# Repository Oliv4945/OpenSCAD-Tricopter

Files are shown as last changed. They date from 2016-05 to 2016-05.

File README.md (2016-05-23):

# OpenSCAD-Tricopter    -    La FraiseVolante
A fully customizable 3D printed tricopter designed thanks to [OpenSCAD](http://www.openscad.org).  
The code is not cristal clear as it was my first "big" project in order to try OpenSCAD for such things, but all parameters can be changed in the file `Variables.scad`, I tried to add warnings in the log for illogical values but always check after modifications. Also, the rod length will be displayed in the log too.

The tricopter works well but the documentation is a work in progress. If needed ask me ;-)

# Files
There is 4 categories
 * Helpers
  * Elements.scad => Contains all elements usefull for design (batteries, ESC, receiver, etc)
  * CCC3DBox.scad => A CC3D case I grabbed [here](http://www.thingiverse.com/thing:95644). Not tested, I only used it for design
 * Assembly.scad => Assembly file, calculates required carbon rod length
 * Variables.scad => All parameters should be tunned here
 * And files with pieces to print
  * ArmHolders.scad
  * BasePlates.scad
  * MotorSupport.scad

# Parts to print
 * armBearingsSeparator_1.stl => 1
 * armBearingsSeparator_2.stl => 1
 * armHolderFront.stl => 2
 * armHolderRearFront.stl => 1
 * armHolderRearRear.stl => 1
 * basePlateLow.stl => 1
 * basePlateMiddle.stl => 1
 * basePlateServo.stl => 1
 * batteryHolder.stl => 1
 * ESCHolder.stl => 2
 * feetPropSaver.stl => Optionnal
 * motorSupport.stl => 3
 * motorSupportFeet.stl => Optionnal

# Parts to buy
 * 3 Motors - 1806 about 2300 kv. I used DYS BE1806-2300kv
 * 3 ESC -  12A. I used [12A Afro ESC](https://www.hobbyking.com/hobbyking/store/%5F%5F62955%5F%5FAfro%5FESC%5F12Amp%5FBEC%5FUltraLite%5FMultirotor%5FESC%5FV3%5FSimonK%5FFirmware%5FUK%5FWarehouse%5F.html)
 * 5030 propellers. Whatever you find, clockwise and anti-clockwise
 * 1 servo motor, the [TGY-9025](https://www.hobbyking.com/hobbyking/store/%5F%5F31879%5F%5FTurnigy%5F8482%5FTGY%5F9025MG%5FMG%5FServo%5F1%5F8kg%5F0%5F09sec%5F11g%5FUK%5FWarehouse%5F.html) works fine and I design the support for it.
 * 10mm OD holow carbon fiber tube - about 35 cm. I used [this one](https://www.hobbyking.com/hobbyking/store/%5F%5F26195%5F%5FCarbon%5FFiber%5FTube%5Fhollow%5F10x750mm%5FUK%5FWarehouse%5F.html)
 * Batteries - 3S from 1.3Ah to 2.2Ah. [This battery](https://www.hobbyking.com/hobbyking/store/%5F%5F32111%5F%5FZIPPY%5FCompact%5F1300mAh%5F3S%5F25C%5FLipo%5FPack%5FUK%5FWarehouse%5F.html) is great, 2.2A works too but it is a bit heavy
 * 1 micro receiver. I use FrSky D4R-II 2.4G 4CH ACCST Telemetry flashed in 8 channels CPPM.
 * 1 flight controller. I used a cheap [CC3D](http://www.openpilot.org/products/openpilot-coptercontrol-platform)
 * 2 bearings - size 10x15x4 mm. Mine are 9.8 inner mm instead of 10, that is why I do not put carbon rod inside but designed a part.
 * Optionnal
  * Video for FPV
   * Holder for a [Sony 600 TVL](http://www.surveilzone.com/fpv/fpv-camera/sony-super-had-ccd-600tvl-fpv-ir-block-camera-2.8mm-lens)
   * Video transmitter
  * Bluetooth to ease configuration, especially if you but the USB port behind the servo like me (Not recommended :p)

Screws are all 3 mm, mainly 6 an 8 mm long (TBC). You can use metal screws but nylon will save weight, and especially act as fuses. It works well !

# Others
There are comments in code to help to understand, but from time to time some names are not explicits. If you change them PR are welcome !  
Thank to the [Brocopter](http://www.thingiverse.com/thing:413639) for some inspiration, especially to add some tape on the rods in order to adjust the motor support.

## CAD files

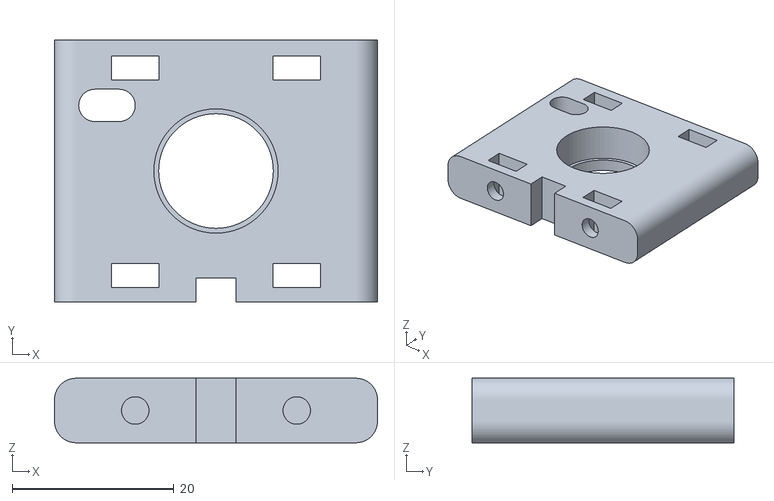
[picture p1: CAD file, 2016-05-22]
TriCopter/armHolderRearFront.stl
40.0 x 32.5 x 8.00

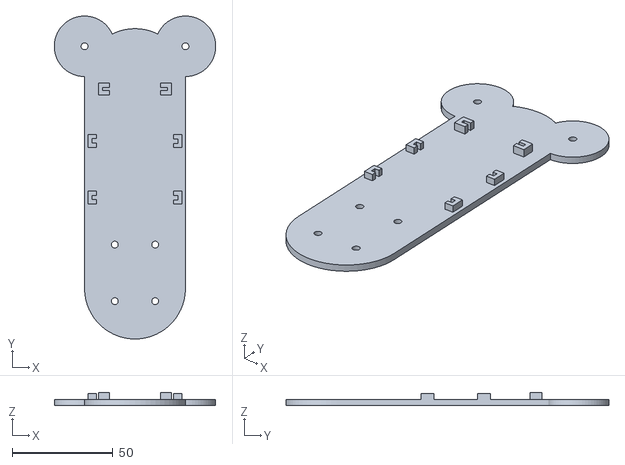
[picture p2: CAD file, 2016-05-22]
TriCopter/basePlateLow.stl
80.0 x 160.0 x 6.50

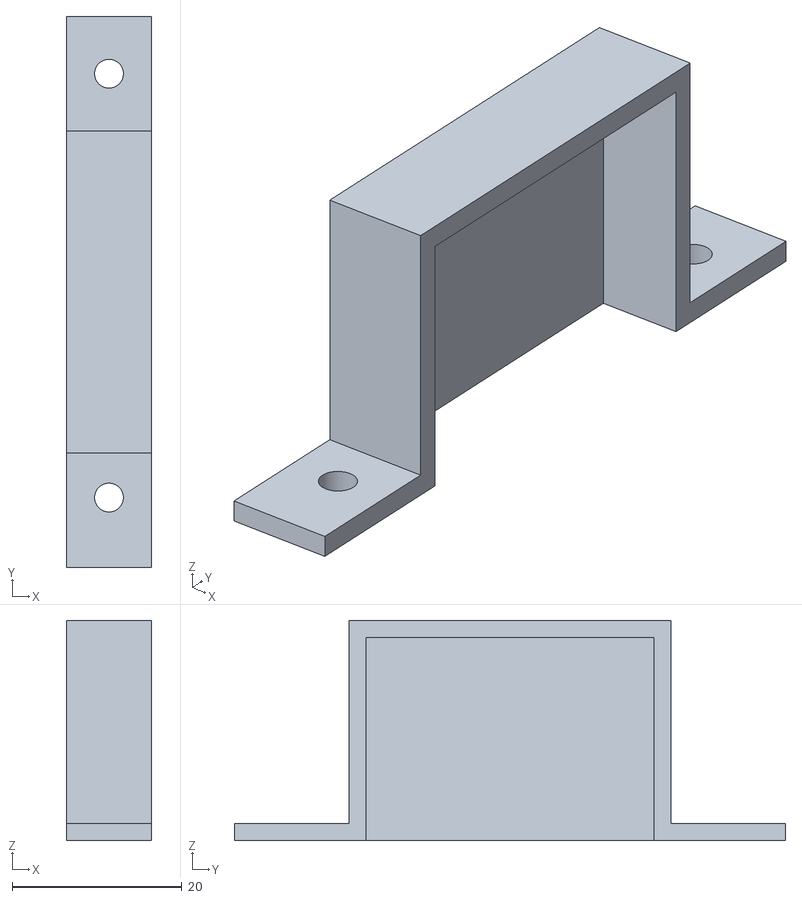
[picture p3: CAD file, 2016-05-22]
TriCopter/batteryHolder.stl
10.0 x 65.0 x 26.0

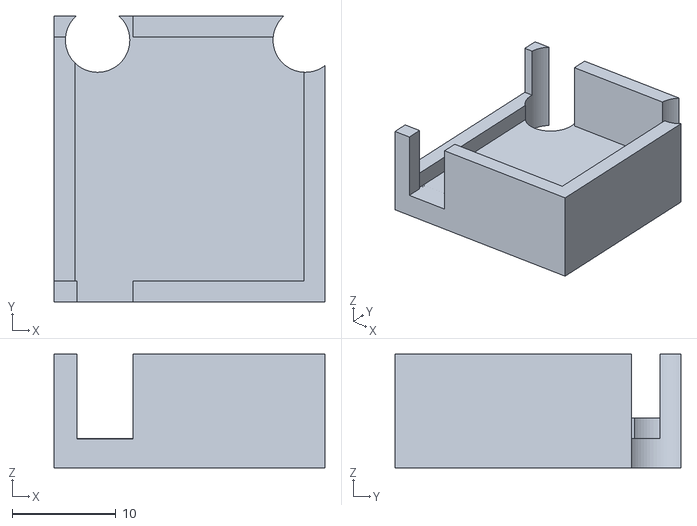
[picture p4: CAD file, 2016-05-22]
TriCopter/basePlateServo.stl
26.1 x 27.5 x 10.9

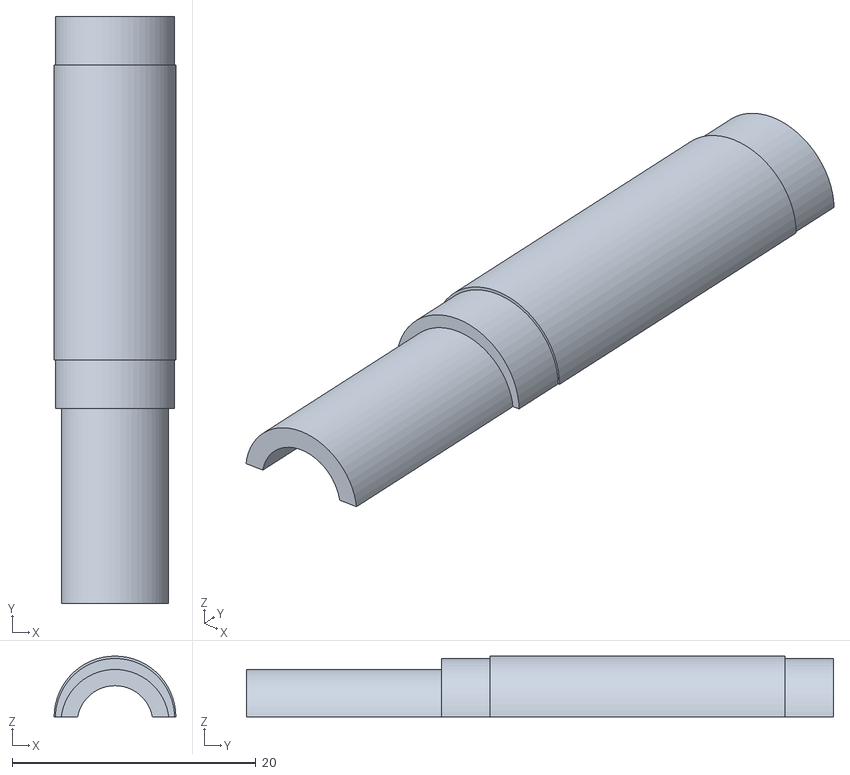
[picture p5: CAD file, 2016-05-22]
TriCopter/armBearingsSeparator_1.stl
10.0 x 48.2 x 5.00

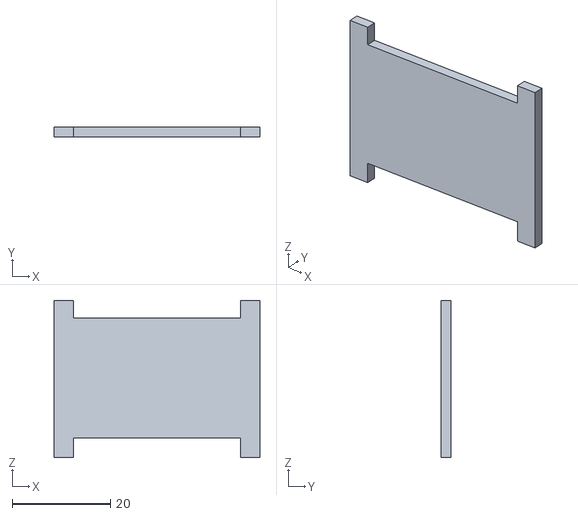
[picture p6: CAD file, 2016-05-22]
TriCopter/ESCHolder.stl
42.0 x 2.00 x 32.1

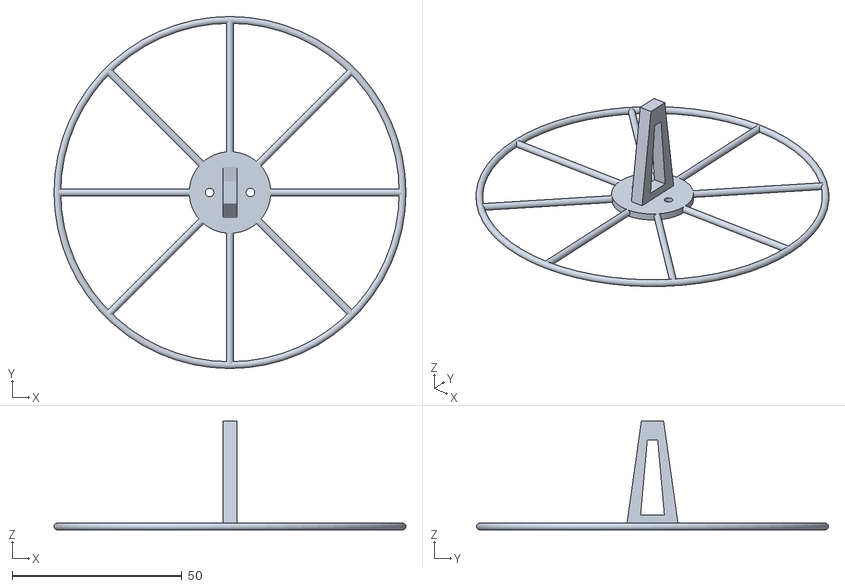
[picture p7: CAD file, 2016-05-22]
TriCopter/feetPropSaver.stl
103.6 x 103.6 x 32.0

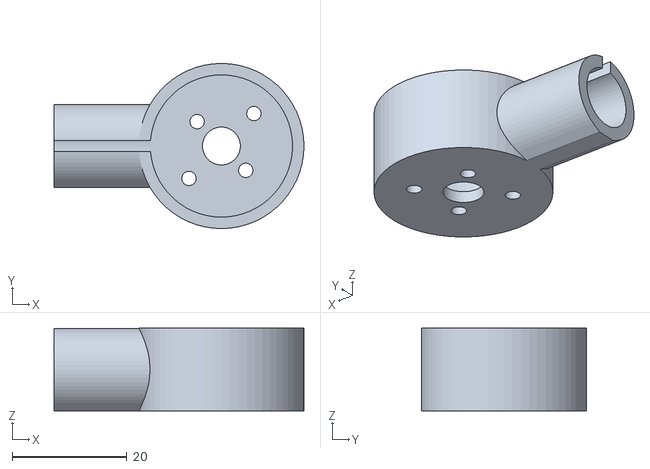
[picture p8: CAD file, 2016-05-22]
TriCopter/motorSupport.stl
43.6 x 28.8 x 14.4

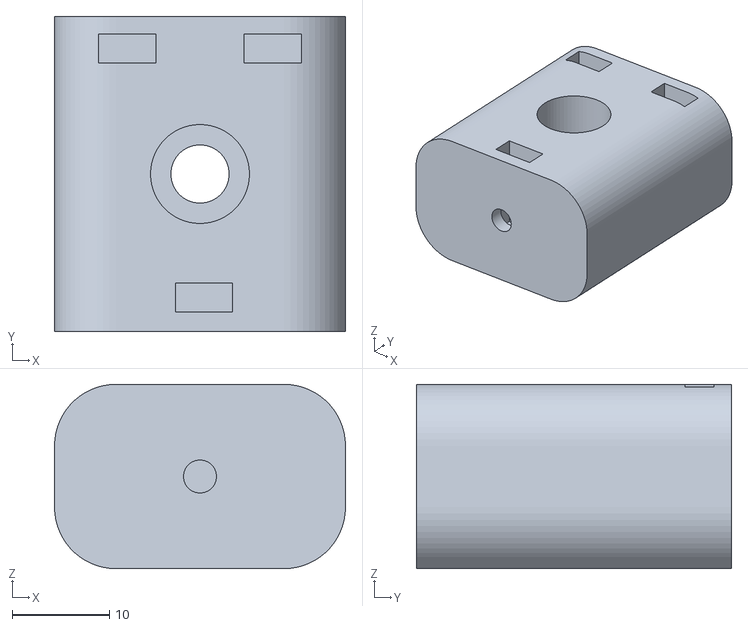
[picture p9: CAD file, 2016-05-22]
TriCopter/armHolderFront.stl
30.0 x 32.5 x 19.0

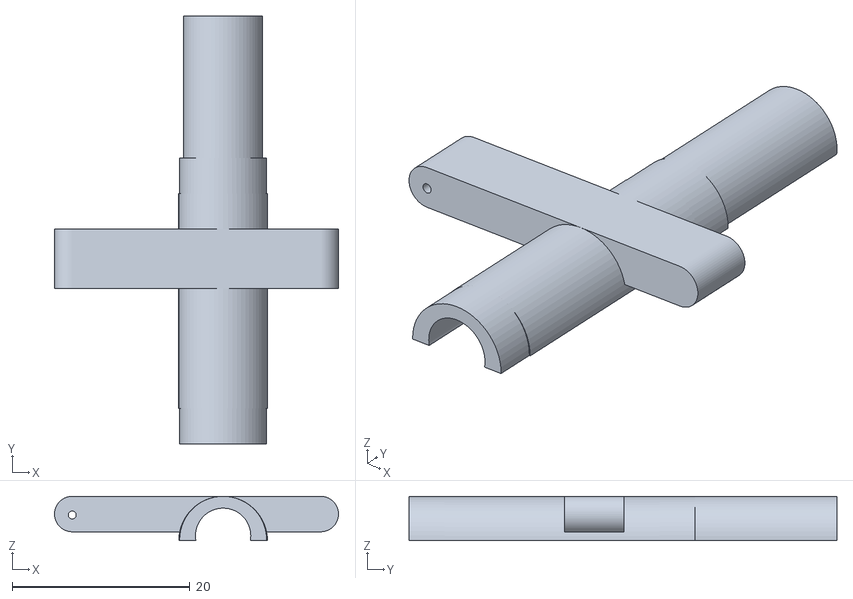
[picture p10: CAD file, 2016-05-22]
TriCopter/armBearingsSeparator_2.stl
32.0 x 48.2 x 5.00

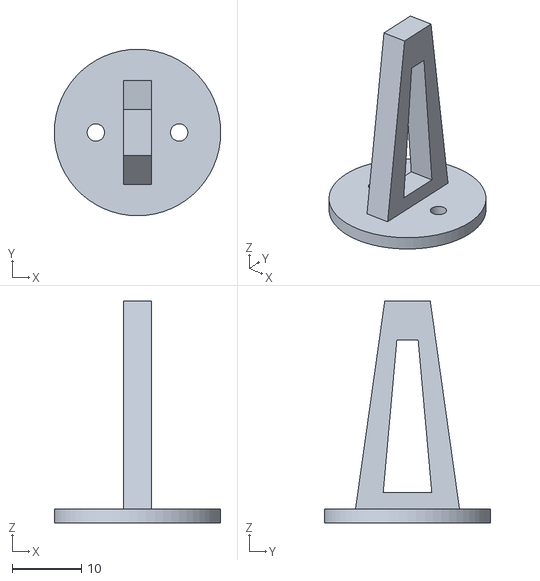
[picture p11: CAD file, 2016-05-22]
TriCopter/motorSupportFeet.stl
24.0 x 24.0 x 32.0

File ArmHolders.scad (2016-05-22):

// Include needed libraries
include <Variables.scad>;
use <Elements.scad>;

// Defines if we want a 'printable file' or a view with elements (motors...)
RENDER = 0;
PRINT = 1;
ASSEMBLY = 2;
view = ASSEMBLY;




module armHolderFront() {
  // Generates warning if needed
  if ( (armScrewLength-basePlateT+wallT+armOD/2)>armHolderH/2 ) {
    echo( "WARNING - Screw to long/arm radius to big, or arm holder not height enough" );
  }
  if ( (basePlateT==(wallT+clearance)) ) {
    echo( "WARNING - Front arm stops have same thickness than baase plate, be carrefull with difference function" );
  }
  
  difference() {
    union () {
      // Add - Main body
      roundedBox( [armHolderFrontW, armHolderFrontD, armHolderH], armHolderFrontD/3);
    }
    // Remove - Arm
    translate( [armHolderFrontW/2, -1, armHolderH/2] )
      rotate( [0, 90, 90] ) cylinder( r=armOD/2+clearance/2, h=armInsideSupport+1 );
    // Remove - Hole for wires
    translate( [armHolderFrontW/2, -1, armHolderH/2] )
      rotate( [0, 90, 90] ) cylinder( r=armOD/2-wallT, h=armInsideSupport*2 );
    
    // Remove - Bottom screw
    translate( [armHolderFrontW/2, armHolderFrontD/2, -basePlateT+1] )
      cylinder( r=armScrewOD/2+clearance, h=armScrewLength+1 );
    // Remove - Top screws
    translate( [armHolderFrontW/4, armHolderFrontD/2, armHolderH+basePlateT-armScrewLength-1] )
      cylinder( r=armScrewOD/2+clearance, h=armScrewLength+1 );
    translate( [armHolderFrontW*3/4, armHolderFrontD/2, armHolderH+basePlateT-armScrewLength-1] )
      cylinder( r=armScrewOD/2+clearance, h=armScrewLength+1 );
    // Remove - Bottom nut
    translate( [(armHolderFrontW-armScrewNutW+clearance*2)/2, -armHolderFrontD/2+armScrewNutW/(sqrt(3)/2)/2+clearance, (armScrewLength-basePlateT)-(armScrewNutH+clearance*2)] )
      cube( [armScrewNutW+clearance*2, armHolderFrontD, armScrewNutH+clearance*2] );
    // Remove - Top nuts
    translate( [(armHolderFrontW/4-armScrewNutW/2-clearance), -armHolderFrontD/2+armScrewNutW/(sqrt(3)/2)/2+clearance, armHolderH-(armScrewLength-basePlateT)+clearance] )
      cube( [armScrewNutW+clearance*2, armHolderFrontD, armScrewNutH+clearance*2] );
    translate( [(armHolderFrontW*3/4-armScrewNutW/2-clearance), -armHolderFrontD/2+armScrewNutW/(sqrt(3)/2)/2+clearance, armHolderH-(armScrewLength-basePlateT)+clearance] )
      cube( [armScrewNutW+clearance*2, armHolderFrontD, armScrewNutH+clearance*2] );
  }
}


module armHolderRear() {
  difference() {
    // Add - Main body
    roundedBox( [armHolderRearW, armHolderRearD, armHolderH], armHolderRearD/3);
    // Remove - Bearing holder
    translate( [armHolderRearW/2, -1, armHolderH/2] )
      rotate( [0, 90, 90] ) cylinder( r=armBearingOD/2-armBearingFlange, h=armHolderRearD+2 );
    translate( [armHolderRearW/2, armHolderRearD-armBearingBore-wallT, armHolderH/2] )
      rotate( [0, 90, 90] ) cylinder( r=armBearingOD/2+clearance, h=armHolderRearD+1 );
    // Remove - Screws
    translate( [armHolderRearW/4, armHolderRearD/2, -basePlateT+1] )
      cylinder( r=armScrewOD/2+clearance, h=armScrewLength+1 );
    translate( [armHolderRearW*3/4, armHolderRearD/2, -basePlateT+1] )
      cylinder( r=armScrewOD/2+clearance, h=armScrewLength+1 );
    translate( [armHolderRearW/4, armHolderRearD/2, armHolderH+basePlateT-armScrewLength-1] )
      cylinder( r=armScrewOD/2+clearance, h=armScrewLength+1 );
    translate( [armHolderRearW*3/4, armHolderRearD/2, armHolderH+basePlateT-armScrewLength-1] )
      cylinder( r=armScrewOD/2+clearance, h=armScrewLength+1 );
    // Remove - Nuts
    translate( [armHolderRearW/4-(armScrewNutW+clearance*2)/2, -1, (armScrewLength-basePlateT)-(armScrewNutH+clearance*2)] )
      cube( [armScrewNutW+clearance*2, armHolderRearD+2, armScrewNutH+clearance*2] );
    translate( [armHolderRearW*3/4-(armScrewNutW+clearance*2)/2, -1, (armScrewLength-basePlateT)-(armScrewNutH+clearance*2)] )
      cube( [armScrewNutW+clearance*2, armHolderRearD+2, armScrewNutH+clearance*2] );
    translate( [armHolderRearW/4-(armScrewNutW+clearance*2)/2, -1, armHolderH-(armScrewLength-basePlateT)+clearance] )
      cube( [armScrewNutW+clearance*2, armHolderRearD+2, armScrewNutH+clearance*2] );
    translate( [armHolderRearW*3/4-(armScrewNutW+clearance*2)/2, -1, armHolderH-(armScrewLength-basePlateT)+clearance] )
      cube( [armScrewNutW+clearance*2, armHolderRearD+2, armScrewNutH+clearance*2] );
    // Remove - Arm servo's zip tie
    translate( [armHolderRearW/2-zipTieW/2, -1, armHolderH-zipTieD] )
      cube( [zipTieW, armHolderRearD+2, zipTieD+1] );
  }
}


module armHolderRearFront() {
  difference() {
    armHolderRear();
    // Remove - Battery wires
    translate( [armHolderRearW/5-wallT*1.5, armHolderRearD+1, armHolderH/4] ) rotate( [90, 0, 0] )
    hull() {
      cylinder( r=wallT, h=armHolderRearD+2);
      translate( [wallT*1.5, 0, 0] )
        cylinder( r=wallT, h=armHolderRearD+2);
    }
  }
}

module armHolderRearRear() {
  difference() {
    armHolderRear();
    // Remove - Battery wires
    translate( [armHolderRearW*4/5, armHolderRearD+1, armHolderH/4] ) rotate( [90, 0, 0] )
    hull() {
      cylinder( r=wallT, h=armHolderRearD+2);
      translate( [wallT*1.5, 0, 0] )
        cylinder( r=wallT, h=armHolderRearD+2);
    }
  }
}

module armBearingsSeparator() {
  difference() {
    union() {
      // Add - main body
      translate( [0, (armOD-armBearingID)/2, 0] ) 
        cylinder( r=armBearingID/2, h=armBearingBore );
      translate( [0, 0, armBearingBore] ) 
        cylinder( r=armOD/2, h=armBearingsSeparatorLength+clearance+wallT*2 );
      translate( [0, (armOD-armBearingID)/2, armBearingBore+armBearingsSeparatorLength+clearance+wallT*2] ) 
        cylinder( r=armBearingID/2, h=armBearingBore );
      // Add - Improve printability & piano wire body
      hull() {
        translate( [armOD/2+wallT*3, armOD/2-wallT, wallT*2+armBearingBore] )
          cylinder( r=wallT, h=armBearingsSeparatorLength/3 );
        translate( [-armOD/2-wallT*6, armOD/2-wallT, wallT*2+armBearingBore] )
          cylinder( r=wallT, h=armBearingsSeparatorLength/3 );
      }
      // Add - Inner of carbon tube
      translate( [0, (armOD-armID)/2, -armBearingBore*4] ) 
        cylinder( r=armID/2, h=armBearingBore*4 );
    }
    // 8.9
    /*
    // Remove - Arm
    translate( [0, 0, -1] )
      cylinder( r=armOD/2+clearance/2, h=armBearingsSeparatorLength+wallT*2+2 );
    // Remove - Screws
    translate( [armOD/2+wallT*2, -wallT*2-1, armBearingsSeparatorLength/3/2+wallT*2] )
      rotate( [270, 0, 0] ) cylinder( r=armScrewOD/2, h=wallT*4+2 );
    translate( [-(armOD/2+wallT*2), -wallT*2-1, armBearingsSeparatorLength/3/2+wallT*2] )
      rotate( [270, 0, 0] ) cylinder( r=armScrewOD/2, h=wallT*4+2 );
    // Remove - Nuts
    translate( [armOD/2+wallT*2, -wallT*2-1, armBearingsSeparatorLength/3/2+wallT*2] )
      rotate( [270, 0, 0] ) cylinder( r=(armScrewNutW*sqrt(3)/2+clearance)/2, h=wallT+1, $fn=6 );
    translate( [-(armOD/2+wallT*2), -wallT*2-1, armBearingsSeparatorLength/3/2+wallT*2] )
      rotate( [270, 0, 0] ) cylinder( r=(armScrewNutW*sqrt(3)/2+clearance)/2, h=wallT+1, $fn=6 );
    */
    // Remove - Steel wire
    translate( [-armOD/2-wallT*6, armBearingID/2-wallT, 0] )
      cylinder( r=armYawSteelWireOD/2, h=armBearingsSeparatorLength );
    // Remove - Inside to allow wires
    // Add - Inner of carbon tube
      translate( [0, (armOD-armID)/2, -armBearingBore*4-1] ) 
        cylinder( r=armID/2-wallT/1.5, h=armBearingsSeparatorLength*4 );
  }
}
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

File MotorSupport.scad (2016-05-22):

// Include needed libraries
include <Variables.scad>;
use <Elements.scad>;

// Set number of facets for arcs
$fn=60;


// Defines if we want a 'printable file' or a view with elements (motors...)
RENDER = 0;
PRINT = 1;
ASSEMBLY = 2;
view = PRINT;


// General design
wallT = 2;
clearance = 0.2;

// Arm
armOD = 10;

// MotorSupports
/*motorOD = 23;
motorScrewOD = 2.1;
motorScrewAlignementD1 = 12;
motorScrewAlignementD2 = 16;
motorAxleOD = 6.2;
armInsideSupport = 20;
feetW = 15;
feetH = 30;
feetT = wallT*2;*/


module motorSupport() {
  supportH = armOD+wallT*2+clearance*2;
  motorCenter = motorOD/2+wallT+clearance+armInsideSupport;
  
  difference() {
    union() {
      // Add - Arm extension
      hull() {
        cylinder( r=supportH/2, h=armInsideSupport+(motorOD+wallT)/2 );
        translate( [-supportH/2, -supportH/4/2, 0] )    // Flat surface to improve printing
          cube( [wallT, supportH/4, armInsideSupport+(motorOD+wallT)/2] );
      }
      // Add - Motor support
      translate( [-supportH/2, 0, motorCenter] )
        rotate( [0, 90, 0] ) cylinder( r=motorOD/2+clearance*2+wallT, h=supportH );
    }
    // Remove - arm - X=0.01 is to avoid removing on same planen
    translate( [0.01, 0, -1] ) cylinder( r=armOD/2+clearance/2, h = armInsideSupport+motorOD/2+1 );
    // Remove - Motor hole
    translate( [-supportH/2+wallT, 0, motorCenter] )
      rotate( [0, 90, 0] ) cylinder( r=motorOD/2+clearance*2, h=supportH );
    // Remove - Motor screws
    translate( [-supportH/2+1, 0, motorCenter] ) rotate( [45, 0, 0] ) rotate( [0, 90, 0] ) {
      for( i = [90, 270] ) {
        rotate( [0, 0, i] ) translate( [motorScrewAlignementD1/2, 0, 0] )
        cylinder( r=motorScrewOD/2+clearance, h=wallT+2, center=true );
      }
      for( i = [0, 180] ) {
        rotate( [0, 0, i] ) translate( [motorScrewAlignementD2/2, 0, 0] )
        cylinder( r=motorScrewOD/2+clearance, h=wallT+2, center=true );
      }
    }
    // Remove - Wire insertion
    translate( [-armOD/2, -wallT/2, -1] )
      cube( [armOD+wallT+2, wallT, armInsideSupport*2] );
    // Remove - Motor axle
    translate( [-supportH+1, 0, motorCenter] ) rotate( [0, 90, 0] )
      cylinder( r=motorAxleOD/2+clearance, h=supportH+2 );
  }
}

module feet() {
  angle = 8;
  holeOD = 3;

  difference() {
    cube( [feetW, feetT, feetH] );
    translate( [-feetW*2, -1, 0] ) rotate( [0, angle, 0] )
      cube( [feetW*2*cos(angle), feetT*2, feetH*2] );
    translate( [feetW, -1, 0] ) rotate( [0, -angle, 0] )
      cube( [feetW*2*cos(angle), feetT*2, feetH*2] );
  }
}


module motorScrews() {
  motorScrewAlignementD = motorScrewAlignementD1;
  union() {
    translate( [motorScrewAlignementD/2, 0, -1 ] )
      cylinder( r=motorScrewOD/2+clearance, h=wallT+2 );
    translate( [-motorScrewAlignementD/2, 0, -1 ] )
      cylinder( r=motorScrewOD/2+clearance, h=wallT+2 );
  }
}

module motorSupportFeet() {
  difference() {
    union() {
      // Add - Support plate
      cylinder( r=motorOD/2, h=wallT );
      translate( [feetT/2, -feetW/2, wallT] ) 
        rotate( [ 0, 0, 90] ) feet( wallT=wallT, feetT=feetT, feetH=feetH );
    }
    // Remove - Motor screws
    motorScrews();
    // Remove - Feet decoration
    resize( [feetT+2, feetW-feetT*2, feetH-feetT*2] )
      translate( [feetT/2, -feetW/2, wallT+feetT] ) rotate( [ 0, 0, 90] ) feet( feetT=feetT );
  }
}

module feetPropSaver() {
  difference() {
    union() {
      // Add - Motor feet
      motorSupportFeet();
      // Add - Structure
      for( i = [0 : 360/8 : 360] ) {
        translate( [0, 0, wallT/2] ) rotate( [90, 0, i] )
          cylinder( h=propOD/2.5, r=wallT/2 );
      // Add - Structure's circle
     translate( [0, 0, wallT/2] ) rotate_extrude( convexity = 10, $fn = 60 )
       translate([propOD/2.5, 0, 0])
         circle( r=wallT/2 );
      }
    }
    // Remove - motor screws
    motorScrews();
  }
}


if ( view == PRINT ) {
  translate( [0, 0, (armOD+wallT*2+clearance*2)/2] )
    rotate( [ 0, 270, 180] ) motorSupport();
  !translate( [-20, 0, 0] ) motorSupportFeet();
  translate( [0, propOD/1.5, 0] ) feetPropSaver();
} 
if ( ( view == RENDER) || ( view == ASSEMBLY) ) {
  translate( [0, 0, 0] ) rotate( [ 0, 270, 180] ) motorSupport();
  translate( [motorOD/2+wallT+armInsideSupport, 0, -(armOD+wallT*2+clearance*2)/2+wallT] )
    rotate( [ 0, 0, 90] ) motorDYS_BE1806();
  translate( [motorOD/2+wallT+armInsideSupport, 0, -(armOD+wallT*2+clearance*2)/2] )
    rotate( [ 180, 0, 90] ) motorSupportFeet();
}

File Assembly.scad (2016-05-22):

// Include needed libraries
include <Variables.scad>;
include <Elements.scad>;
include <MotorSupport.scad>;
include <ArmHolders.scad>;
include <BasePlates.scad>;

// Defines if we want a 'printable file' or a view with elements (motors...)
view = -1;
// Define if the front arms are folded
viewFoldedArms = FALSE;

 
module armFrontL( armLength = 100 ) {
	union() {
		translate( [armHolderFrontD, 0, 0] ) rotate( [0, 0, 90] ) armHolderFront();
  	translate( [armHolderFrontD-armInsideSupport, armHolderFrontW/2, armHolderH/2] ) rotate( [0, 90, 0] )
    	color( "DarkSlateGray") hollowCylinder( OD=armOD, ID=armID, length = armLength );
		translate( [armHolderFrontD-armInsideSupport+armLength-armInsideSupport, armHolderFrontW/2, armHolderH/2] )
    	rotate( [ 0, 270, 180] ) motorSupport( armInsideSupport=armInsideSupport );
  	
		translate( [armHolderFrontD-armInsideSupport+armLength+clearance+wallT+motorOD/2, armHolderFrontW/2, -7.5+wallT+armHolderH/2] )
    	rotate( [ 0, 0, 0] ) motorDYS_BE1806();
  	translate( [armHolderFrontD-armInsideSupport+armLength+clearance+wallT+motorOD/2, armHolderFrontW/2, -7.5+armHolderH/2] )
    	rotate( [ 180, 0, 90] ) motorSupportFeet();
  	
	}
}

module armFrontR( armLength = 100 ) {
	union() {
		translate( [armHolderFrontD, armHolderFrontW, 0] ) rotate( [0, 0, 90] ) mirror( [1, 0, 0] ) armHolderFront();
  	translate( [armHolderFrontD-armInsideSupport, armHolderFrontW/2, armHolderH/2] ) rotate( [0, 90, 0] )
    	color( "DarkSlateGray") hollowCylinder( OD=armOD, ID=armID, length = armLength );
		translate( [armHolderFrontD-armInsideSupport+armLength-armInsideSupport, armHolderFrontW/2, armHolderH/2] )
    	rotate( [ 0, 270, 180] ) motorSupport( armInsideSupport=armInsideSupport );
  	
		translate( [armHolderFrontD-armInsideSupport+armLength+clearance+wallT+motorOD/2, armHolderFrontW/2, -7.5+wallT+armHolderH/2] )
    	rotate( [ 0, 0, 0] ) motorDYS_BE1806();
  	translate( [armHolderFrontD-armInsideSupport+armLength+clearance+wallT+motorOD/2, armHolderFrontW/2, -7.5+armHolderH/2] )
    	rotate( [ 180, 0, 90] ) motorSupportFeet();
  	
	}
}
module armFrontAssembly() {
  // Left
  translate( [0,
							basePlateArmHolderFrontPivotD,
							basePlateT]
            )
		rotate( [0, 0, 180-armFrontAngle+viewFoldedArms*armFrontAngleFolded] )
      translate( [-armHolderFrontD/2, -armHolderFrontW/2, 0] ) armFrontL( armLengthFront );
  // Right
  translate( [basePlateW,
							basePlateArmHolderFrontPivotD,
							basePlateT]
            )
		rotate( [0, 0, armFrontAngle-viewFoldedArms*armFrontAngleFolded ] )
      translate( [-armHolderFrontD/2, -armHolderFrontW/2, 0] ) armFrontR( armLengthFront );
}

module armRearAssembly() {
 armHolderRearFront();
  translate( [armHolderRearW, armHolderRearD*2+armBearingsSeparatorLength ,0 ] )
    rotate( [0, 0, 180] ) armHolderRearRear();
  translate( [armHolderRearW/2, wallT, armHolderH/2] )    // Bearings
    rotate( [0, 90, 90] ) color( "LightGrey") {
      hollowCylinder( OD=armBearingOD, ID=armBearingID, length=armBearingBore );
      translate( [0, 0, armBearingsSeparatorLength+wallT*2+armBearingBore] ) 
      hollowCylinder( OD=armBearingOD, ID=armBearingID, length=armBearingBore );
  }
  translate( [armHolderRearW/2, -armLengthRear+(armHolderRearD*2+armBearingsSeparatorLength), armHolderH/2] ) rotate( [0, 90, 90] )
    color( "DarkSlateGray")  hollowCylinder( OD=armOD, ID=9, length=armLengthRear );      // CF rod
  translate( [armHolderRearW/2, wallT+armBearingBore, armHolderH/2] )
    rotate( [270, 0, 0] ) armBearingsSeparator();
  translate( [armHolderRearW/2,
              -armLengthRear+(armHolderRearD*2+armBearingsSeparatorLength)+armInsideSupport,
              armHolderH/2
            ] )
    	rotate( [ 0, 270, 90] ) motorSupport( armInsideSupport=armInsideSupport );
  translate( [armHolderRearW/2, -armLengthRear+(armHolderRearD*2+armBearingsSeparatorLength)-motorOD/2-wallT-clearance, -7.5+wallT+armHolderH/2] )
    motorDYS_BE1806();
}

module all() {
  echo( "Front arm length (mm): ", armLengthFront );
  echo( "Rear arm length (mm): ", armLengthRear );
  if ( (pivotToMotorLength-armHolderFrontW/2)<propW/2 ) {
    echo( "<b>WARNING</b> - Front - Props to wide or motor circle diameter to small" );
  }
  if ( abs((CC3DCenterX-armMotorCircleD/2))<propW/2 ) {
    echo( "<b>WARNING</b> - Rear - Props to wide or motor circle diameter to small" );
  }
  
  armFrontAssembly();
	translate( [basePlateW/2-armHolderRearW/2, basePlateW/2-basePlateW/8-armHolderRearD/2, basePlateT] ) armRearAssembly();
  basePlateLow();
  translate( [0, 0, basePlateT+armHolderH] ) basePlateMiddle();
  // ESC
  translate( [35, basePlateW/2+armBearingsSeparatorLength+armHolderRearD+wallT*19+ESCH, basePlateT+6] ) 
    rotate( [0, -90, 90] ) ESCAfro12A();
  translate( [35, basePlateW/2+armBearingsSeparatorLength+armHolderRearD+wallT*8, basePlateT+6] ) 
    rotate( [0, -90, 90] ) ESCAfro12A();
  translate( [35, basePlateW/2+armBearingsSeparatorLength+armHolderRearD+wallT*6+ESCH*2, basePlateT+6] )
    rotate( [0, -90, 90] ) ESCAfro12A();
  // ESC Holders
  translate( [wallT*2, basePlateW/2+armBearingsSeparatorLength+7*wallT+armHolderRearD/2+ESCH, basePlateT] ) ESCHolder();
  translate( [wallT*2, basePlateW/2+armBearingsSeparatorLength+15*wallT+armHolderRearD/2+ESCH*3, basePlateT] ) ESCHolder();
  // CC3D
  translate( [ basePlateW/2-40/2, 
               basePlateW/2-basePlateW/8+armBearingsSeparatorLength+2*wallT+armHolderRearD+wallT*2, 
               basePlateT*2+armHolderH  ] )
    color( "darkgreen" ) CC3DBox();
  // Receiver
  translate( [basePlateW/2-40/2,
              basePlateW/2+armBearingsSeparatorLength+16*wallT+armHolderRearD/2+ESCH*4,
              basePlateT+wallT*2
            ] )
    rotate( [90, 0, 0] ) receiverFrSkyD4RII();
  // Base plate servo
  translate( [0, 0, basePlateT*2+armHolderH] ) basePlateServo();
  // Servo
  translate( [ armServoH+basePlateW/2-wallT*6,
            armServoW+basePlateW/2-basePlateW/8+armHolderRearD+wallT-(armServoW-armServoD/2)+armServoArmD, 
            basePlateT*2+armHolderH+armScrewHeadH+clearance
          ] )
    rotate( [90, 0, 270] ) color( "DodgerBlue") 
      servo( size=[armServoW, armServoD, armServoH]  );
  // Props
  %translate( [-pivotToMotorLength*cos(armFrontAngle), basePlateArmHolderFrontPivotD+pivotToMotorLength*sin(armFrontAngle), armHolderH+basePlateT] )
    color( "orange", 0.1 ) circle( r=propW/2 );
  %translate( [basePlateW+pivotToMotorLength*cos(armFrontAngle), basePlateArmHolderFrontPivotD+pivotToMotorLength*sin(armFrontAngle), armHolderH+basePlateT] )
    color( "orange", 0.1 ) circle( r=propW/2 );
  %translate( [basePlateW/2, CC3DCenterX-armMotorCircleD/2, armHolderH+basePlateT] )
    color( "orange", 0.1 ) circle( r=propW/2 );
  // Camera
  translate( [basePlateW/2, basePlateD-cameraH*1.4, basePlateT+cameraSize/2] ) 
    rotate( [-90, 0, 0] ) sony600TVL();
  // Lipo
  translate( [(basePlateW-lipoD)/2, (basePlateD-lipoW)/2, 0] )
    rotate( [0, 180, -90] ) lipo();
  // Lipo holder
  translate( [-((basePlateW+armHolderFrontW/2)-(lipoD+wallT*2))/4, 
              basePlateD-armHolderFrontW/3,
              0 ] )
    rotate( [0, 180, 180] ) batteryHolder();
  }


all();


//CC3D();

//motorSupport();

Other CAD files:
TriCopter/basePlateMiddle.stl
TriCopter/armHolderRearRear.stl
BasePlates.scad
CC3DBox.scad
Elements.scad
Variables.scad
